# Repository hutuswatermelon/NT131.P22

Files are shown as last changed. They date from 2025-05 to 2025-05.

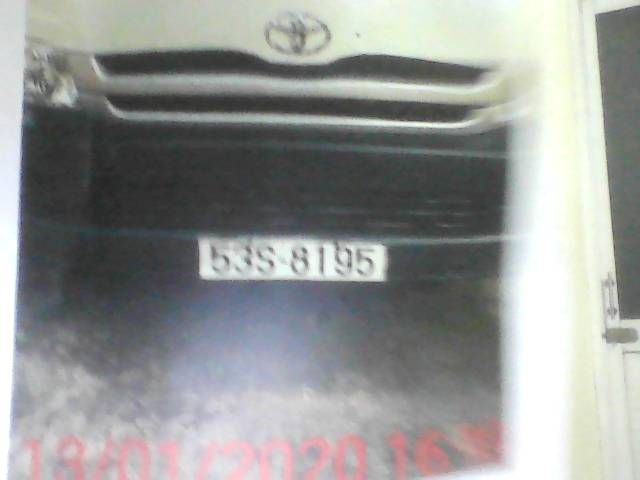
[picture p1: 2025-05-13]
back_end/uploads/1746991411067-entry-1746991411064.jpg

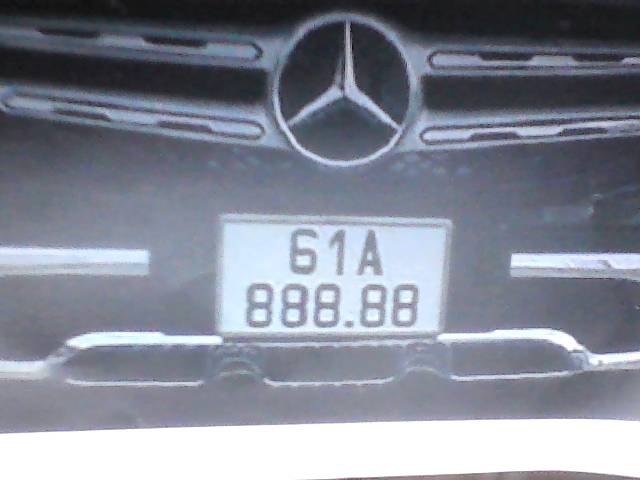
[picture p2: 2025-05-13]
back_end/uploads/1746958516057-entry-1746958516046.jpg

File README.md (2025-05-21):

# HỆ THỐNG BÃI ĐỖ XE TỰ ĐỘNG SỬ DỤNG ESP8266

## Thông tin môn học
- **Môn học:** Hệ thống nhúng mạng không dây
- **Mã lớp:** NT131.P22

## Thành viên nhóm
- Cáp Hữu Tú - 23521696
- Huỳnh Ngọc Ngân Tuyền - 23521753
- Nguyễn Tài Quang - 23521287

## Mô tả dự án
Dự án "Hệ thống bãi đỗ xe tự động" được xây dựng nhằm mô phỏng và triển khai một giải pháp quản lý bãi đỗ xe thông minh. Hệ thống sử dụng công nghệ RFID để xác thực xe vào/ra, kết hợp với nhận dạng biển số xe tự động qua camera. Trạng thái của bãi xe, thông tin xe, và các thao tác quản lý được hiển thị và điều khiển thông qua một giao diện web trực quan.

## Công nghệ sử dụng
- **Phần cứng:**
    - ESP8266 (NodeMCU 1.0 (ESP-12E Module)
    - Đầu đọc RFID MFRC522 và thẻ RFID
    - Động cơ Servo để điều khiển rào chắn (barrier)
    - Cảm biến hồng ngoại để phát hiện trạng thái đỗ xe (trong mô hình này, trạng thái chỗ đỗ được cập nhật từ ESP8266 dựa trên logic vào/ra kết hợp quét chỗ đỗ định kỳ).
    - Webcam để chụp ảnh biển số.
- **Phần mềm:**
    - **Arduino/C++:** Lập trình cho ESP8266 ([Arduino/car_parking/car_parking.ino](Arduino/car_parking/car_parking.ino)).
    - **Node.js & Express.js (Backend):** Xây dựng API, xử lý logic nghiệp vụ, giao tiếp với ESP8266, quản lý cơ sở dữ liệu, và phục vụ Server-Sent Events (SSE) ([back_end/server.js](back_end/server.js)).
    - **MongoDB:** Cơ sở dữ liệu NoSQL để lưu trữ thông tin xe, lịch sử vào ra.
    - **HTML, CSS, JavaScript (Frontend):** Giao diện người dùng tương tác với hệ thống ([front_end/index.html](front_end/index.html), [front_end/frontend.js](front_end/frontend.js), [front_end/style.css](front_end/style.css)).
    - **Python & FastAPI (License Plate Recognition Service):** Dịch vụ API riêng biệt để nhận dạng ký tự từ ảnh biển số xe ([back_end/License-Plate-Recognition/plate_recognition_service.py](back_end/License-Plate-Recognition/plate_recognition_service.py)).
- **Giao tiếp:**
    - HTTP requests (ESP8266 <-> Node.js, Frontend <-> Node.js, Node.js <-> Python LPR Service).
    - Server-Sent Events (Node.js -> Frontend) để cập nhật dữ liệu thời gian thực.

## Tính năng chính
- **Quản lý xe vào/ra:**
    - Xác thực xe qua thẻ RFID.
    - Tự động chụp ảnh và nhận dạng biển số xe khi xe vào/ra.
    - So sánh biển số xe vào và biển số đăng ký.
    - So sánh biển số xe ra với biển số đã ghi nhận lúc vào.
    - Điều khiển rào chắn tự động.
- **Quản lý bãi xe:**
    - Hiển thị số chỗ trống, số chỗ đã chiếm dụng.
    - Hiển thị danh sách xe đang có trong bãi.
    - Ghi nhận lịch sử các lượt gửi xe (thời gian vào, thời gian ra, biển số, RFID).
- **Giao diện người dùng (Web):**
    - Hiển thị hình ảnh camera (giả lập qua webcam client-side).
    - Hiển thị thông tin biển số xe vào/ra, hình ảnh biển số.
    - Cập nhật trạng thái bãi xe và danh sách xe theo thời gian thực.
    - Cho phép quản lý viên thao tác thủ công (ví dụ: mở cổng, chuyển chế độ RFID).
    - Chức năng xóa toàn bộ dữ liệu xe và lịch sử.
- **Tích hợp module nhận dạng biển số:**
    - Sử dụng một service Python riêng biệt để xử lý nhận dạng biển số.

## Trích dẫn phần Project được sử dụng cho nhận diện biển số
    https://github.com/buiquangmanhhp1999/License-Plate-Recognition

## Hướng phát triển tương lai
**Phần cứng:**
 - *Nâng cấp bộ xử lý trung tâm:*
    - Thay thế ESP8266 bằng ESP32 hoặc bộ xử lý mạnh hơn tuỳ vào quy mô bãi đỗ nhằm cải thiện hiệu suất điều khiển và khả năng xử lý dữ liệu.

- *Mở rộng hệ thống vào/ra:*
    - Thiết kế hệ thống có 2 cổng vào và 2 cổng ra để tăng lưu lượng xe và tối ưu hóa luồng giao thông.

- *Tích hợp camera AI:*
    - Nhận diện biển số: Sử dụng camera mini kết hợp với thuật toán học máy để nhận diện biển số xe tự động.
    - Giám sát toàn bãi xe: Camera giám sát toàn cảnh kết hợp AI nhằm phát hiện và nhận diện chính xác các xe đang đỗ, kể cả khi bị che khuất bởi vật thể khác.

- *Cảm biến môi trường:*
    - Cảm biến ánh sáng: Tự động bật/tắt hệ thống chiếu sáng theo điều kiện ánh sáng môi trường.
    - Cảm biến nhiệt: Kết hợp hệ thống cảnh báo và kích hoạt hệ thống phòng cháy chữa cháy khi phát hiện nhiệt độ bất thường.

- *Mở rộng mô hình bãi giữ xe phân tầng:*
    - Hỗ trợ quản lý bãi xe nhiều tầng, tích hợp bản đồ định vị ô đỗ xe và ghi nhớ vị trí xe đã đỗ.

**Phần mềm:**
- *Cho quản lý bãi xe:*
    - Quản lý đồng thời nhiều bãi đỗ xe.
    - Theo dõi tình trạng bãi xe theo thời gian thực.
    - Hỗ trợ điều khiển các chức năng của bãi xe từ xa thông qua phần mềm quản lý.

- *Cho người dùng (người cần đỗ xe):*
    - Ứng dụng di động thân thiện, tích hợp GPS.
    - Ứng dụng AI/học máy để gợi ý các bãi đỗ gần nhất còn trống, đồng thời cân nhắc chi phí đỗ xe phù hợp.
    - Cho phép người dùng đăng ký và giữ chỗ đỗ xe trực tuyến trước hoặc ngay khi đến bãi đỗ.

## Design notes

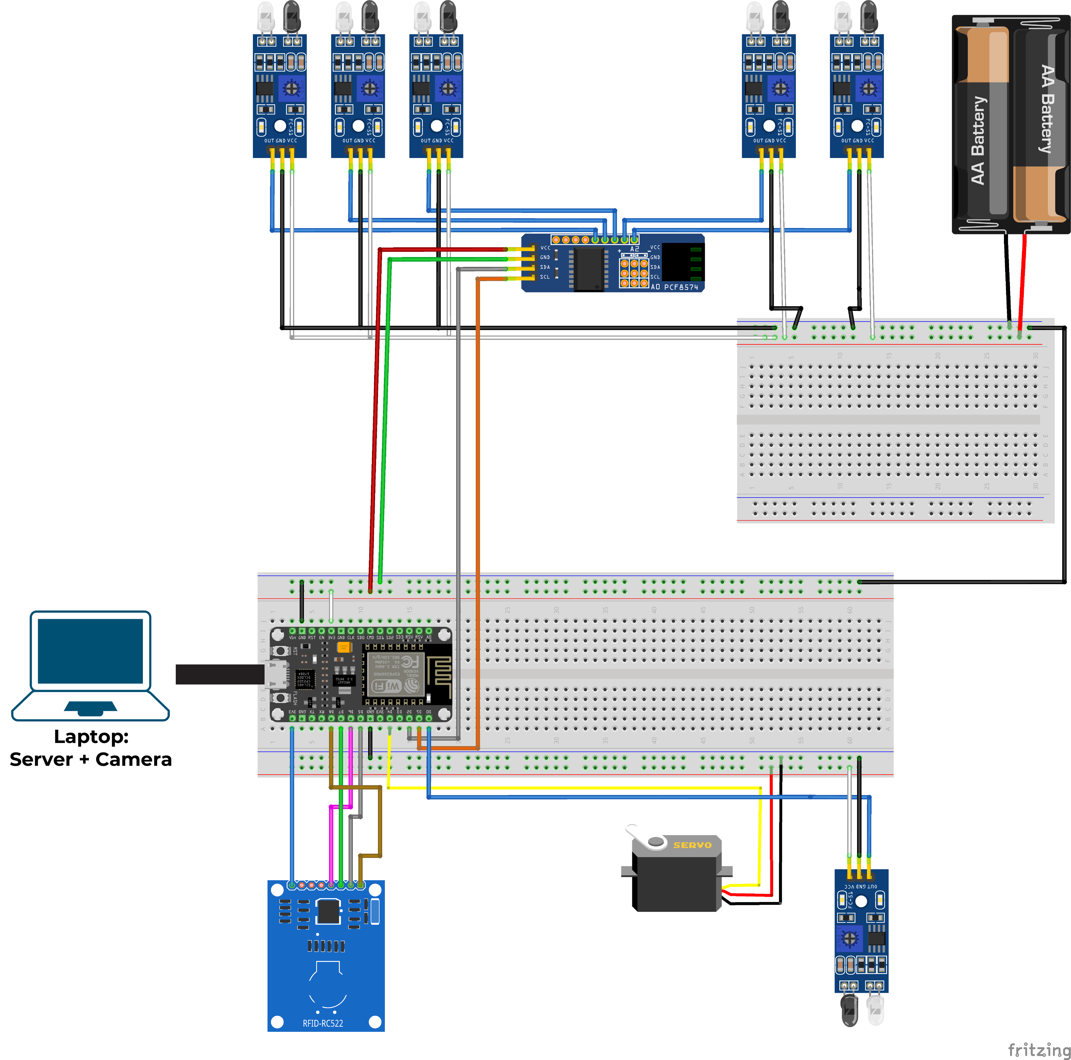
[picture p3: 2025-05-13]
Breadboard.png

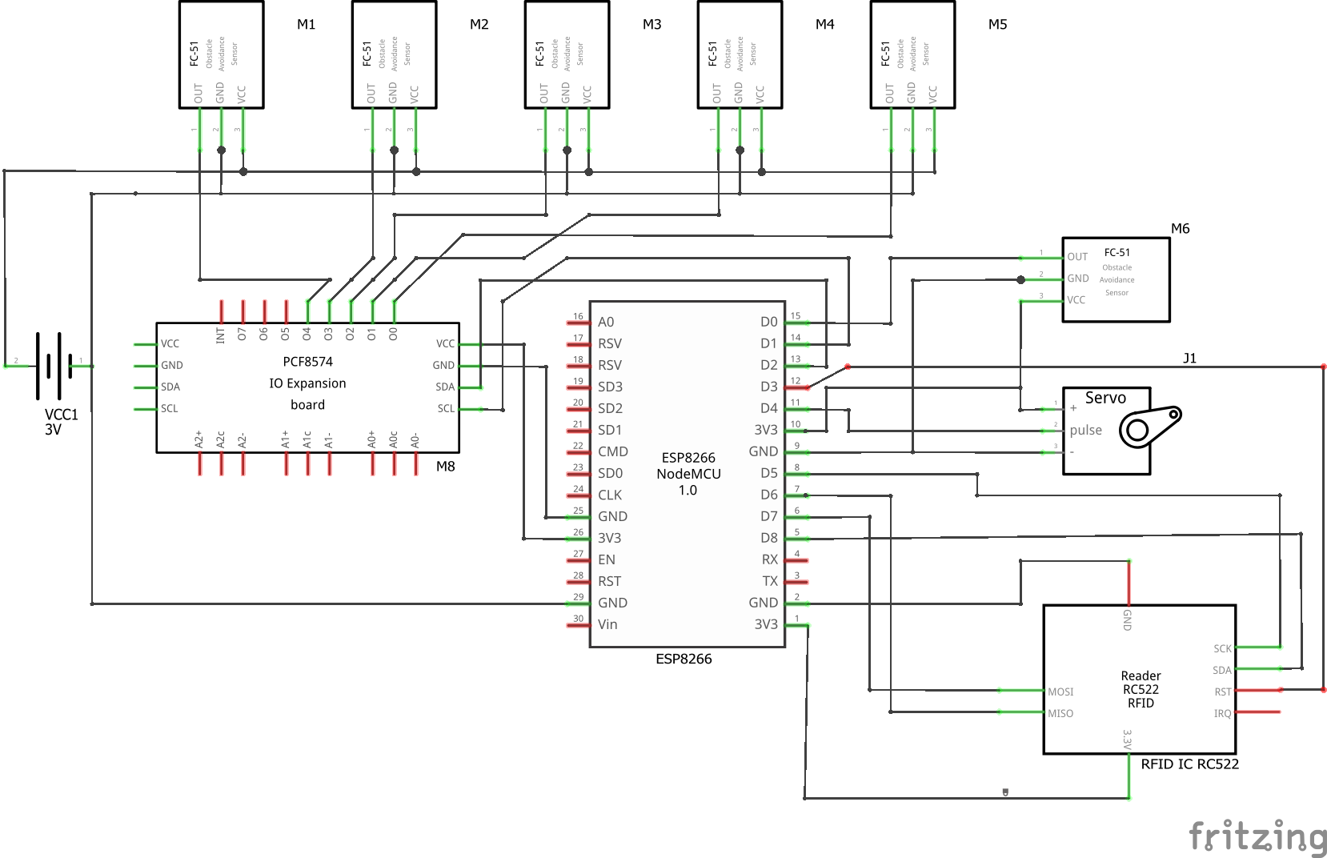
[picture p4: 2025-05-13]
Sơ đồ nguyên lý.png

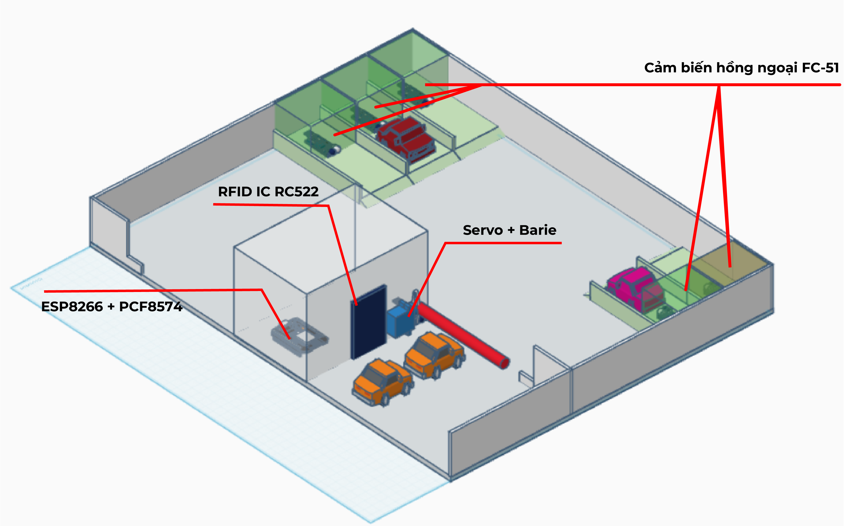
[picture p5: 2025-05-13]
Mô hình.png

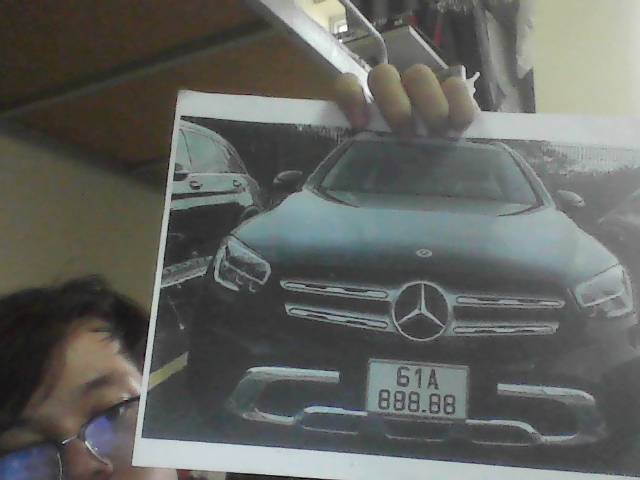
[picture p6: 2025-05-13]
back_end/uploads/1747042774266-entry-1747042774261.jpg

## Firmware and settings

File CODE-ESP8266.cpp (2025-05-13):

#include <ESP8266WiFi.h>
#include <ESP8266HTTPClient.h>
#include <WiFiClient.h>
#include <SPI.h>
#include <MFRC522.h>
#include <Wire.h>
#include <Servo.h>
#include <PCF8574.h> 
#include <ArduinoJson.h>
#include <ESP8266WebServer.h> // Added for ESP to act as a server

// ====== CONFIGURATION ======
const char* WIFI_SSID     = "CPS";
const char* WIFI_PASSWORD = "2444nam678";
const char* SERVER_HOST   = "http://192.168.243.134:3000";

WiFiClient client;

// PCF8574 I/O Expander
PCF8574 pcf8574(0x20);

#define ir_open  D0 // OUT - GPIO16 (D0 trên NodeMCU)

// RFID
#define RST_PIN  D3 // RST MFRC522 - GPIO0 (D3 NodeMCU)
#define SS_PIN   D8// SS (SDA/CS) MFRC522 - GPIO15 (D8 NodeMCU - Hardware CS)
MFRC522 mfrc522(SS_PIN, RST_PIN);

// Servo
#define SERVO_OPEN_GATE_PIN  D4 //  GPIO2 (D4 NodeMCU)
Servo openGateServo;

// ESP Web Server
ESP8266WebServer espHttpServer(80); // ESP will listen on port 80 for commands

// Constants
#define MAX_SLOT 5
#define BARRIER_CLOSED  150
#define BARRIER_OPENED  0

// Represents occupied state for the string (sensor LOW means occupied)
#define SLOT_STATE_OCCUPIED '1'
#define SLOT_STATE_EMPTY    '0'

#define HTTP_TIMEOUT 15000
int slot = 0;
bool waitingToCloseOpen = false;
unsigned long openStartTime = 0;

String uidToString(MFRC522& reader) {
  String s = "";
  for (byte i = 0; i < reader.uid.size; i++) {
    if (reader.uid.uidByte[i] < 0x10) s += "0";
    s += String(reader.uid.uidByte[i], HEX);
  }
  s.toUpperCase();
  return s;
}

// Notify server and get slots
// Changed endpoint to /api/rfid-request
bool notifyServer(const char* path, const String& uid, int &updated_slots_from_server) { 
  if (WiFi.status() != WL_CONNECTED) {
    Serial.println("WiFi not connected. Cannot notify server.");
    return false;
  }

  HTTPClient http;
  WiFiClient client; 

  String url = String(SERVER_HOST) + path + "?uid=" + uid;
  Serial.println("Sending to server: " + url); 

  http.begin(client, url);
  http.setTimeout(HTTP_TIMEOUT); 
  int httpCode = http.GET();

  bool openGateStatus = false;
  String serverMessage = "No response or error";

  if (httpCode > 0) {
    Serial.printf("[HTTP] GET... code: %d\n", httpCode);
    String payload = http.getString(); // Get payload for debugging
    Serial.println("Raw server response: " + payload);

    if (httpCode == HTTP_CODE_OK) {
      DynamicJsonDocument doc(512);
      DeserializationError error = deserializeJson(doc, payload);

      if (error) {
        Serial.print(F("deserializeJson() failed: "));
        Serial.println(error.f_str());
        serverMessage = "JSON parsing error";
      } else {
        openGateStatus = doc["openGate"] | false;
        updated_slots_from_server = doc["slots"] | -1; // Default to -1 if not present
        serverMessage = doc["message"] | "No message from server";
        String plate = doc["licensePlate"] | "N/A";
        // Log more details from server if available (e.g., for exit)
        if (doc.containsKey("fee")) {
            int fee = doc["fee"];
            serverMessage += " Plate: " + plate + ". Fee: " + String(fee) + " VND.";
        } else {
            serverMessage += " Plate: " + plate + ".";
        }
      }
    } else { // Handle other HTTP codes e.g. 400, 404, 500
        serverMessage = "Server error: HTTP " + String(httpCode);
        DynamicJsonDocument errorDoc(256);
        DeserializationError error = deserializeJson(errorDoc, payload);
        if (!error && errorDoc.containsKey("message")) {
            serverMessage = errorDoc["message"].as<String>();
        }
    }
  } else {
    Serial.printf("[HTTP] GET... failed, error: %s\n", http.errorToString(httpCode).c_str());
    serverMessage = "HTTP request failed: " + String(http.errorToString(httpCode).c_str());
  }
  http.end();
  
  Serial.println("Server final message: " + serverMessage);
  Serial.print("Open gate status: "); Serial.println(openGateStatus ? "Yes" : "No");
  Serial.print("Slots from server: "); Serial.println(updated_slots_from_server);

  return openGateStatus;
}

// Servo control
void openGate(Servo& gate) {
  gate.attach(SERVO_OPEN_GATE_PIN);
  Serial.println("Command received: Opening gate."); // Log manual open
  for (int pos = BARRIER_CLOSED; pos >= BARRIER_OPENED; pos -= 2) { // Assuming BARRIER_CLOSED is higher angle
    gate.write(pos);
    delay(20);
  }
  // After opening, set flags as if RFID opened it, to allow auto-close logic
  gate.detach();
  waitingToCloseOpen = true;
  openStartTime = millis();
  Serial.println("Gate opened manually. Waiting for auto-close conditions.");
}

void closeGate(Servo& gate) {
  gate.attach(SERVO_OPEN_GATE_PIN);
  Serial.println("Closing gate.");
  for (int pos = BARRIER_OPENED; pos <= BARRIER_CLOSED; pos += 2) { // Assuming BARRIER_OPENED is lower angle
    gate.write(pos);
    delay(20); 
  }
  gate.detach();
}

// Returns a string representing the state of each slot
// '1' for occupied, '0' for empty
String getIndividualSlotStatesString() {
  String states = "";
  Serial.println("--- Checking Individual Slot Status (PCF8574) ---");
  for (int i = 0; i < MAX_SLOT; i++) {
    uint8_t pinState = pcf8574.read(i); // Assuming LOW means sensor detected (occupied)
    if (pinState == LOW) {
      states += SLOT_STATE_OCCUPIED;
      Serial.print("Slot P"); Serial.print(i); Serial.println(" -> Occupied (1)");
    } else {
      states += SLOT_STATE_EMPTY;
      Serial.print("Slot P"); Serial.print(i); Serial.println(" -> Empty (0)");
    }
  }
  Serial.print("Individual Slot States String: "); Serial.println(states);
  Serial.println("---------------------------------------------");
  return states;
}

void sendSlotInfoToServer() {
  String slotStatesString = getIndividualSlotStatesString();

  if (WiFi.status() == WL_CONNECTED) {
    HTTPClient http;
    WiFiClient client; 
    // Send individual slot states AND ESP's IP address
    String espIP = WiFi.localIP().toString();
    String url = String(SERVER_HOST) + "/updateSlots?states=" + slotStatesString + "&total=" + String(MAX_SLOT) + "&ip=" + espIP;
    
    Serial.println("Sending individual slot states and IP to server: " + url);

    http.begin(client, url); 
    http.setTimeout(HTTP_TIMEOUT); 
    int code = http.GET();
    if (code > 0) {
        Serial.printf("[HTTP] Slot states update GET... code: %d\n", code);
        if (code == HTTP_CODE_OK) {
            String payload = http.getString();
            Serial.println("Slot states update server response: " + payload);
        }
    } else {
        Serial.printf("[HTTP] Slot states update GET... failed, error: %s\n", http.errorToString(code).c_str());
    }
    http.end();
    Serial.print("Individual slot states sent to server: ");
    Serial.println(slotStatesString);
  }
}

// Handler for manual gate control commands from Node.js server
void handleGateControl() {
  String action = espHttpServer.arg("action");
  Serial.print("ESP received /control-gate command. Action: ");
  Serial.println(action);

  if (action == "open") {
    openGate(openGateServo);
    espHttpServer.send(200, "text/plain", "Gate opening command received by ESP.");

  } else if (action == "close") {
    closeGate(openGateServo);
    waitingToCloseOpen = false;
    espHttpServer.send(200, "text/plain", "Gate closing command received by ESP.");
  }
  else {
    espHttpServer.send(400, "text/plain", "Invalid action. Use 'open' or 'close'.");
  }
}

void setup() {
  Serial.begin(115200);
  while (!Serial);
  Serial.println("\nBooting...");

  SPI.begin();
  mfrc522.PCD_Init();
  Serial.println("MFRC522 initialized.");

  WiFi.mode(WIFI_STA);
  WiFi.begin(WIFI_SSID, WIFI_PASSWORD);
  Serial.print("Connecting to WiFi ");
  Serial.print(WIFI_SSID);
  unsigned long wifiConnectStart = millis();
  while (WiFi.status() != WL_CONNECTED && millis() - wifiConnectStart < 15000) {
    delay(500);
    Serial.print(".");
  }
  if (WiFi.status() == WL_CONNECTED) {
    Serial.println("\nWiFi connected!");
    Serial.print("IP Address: ");
    Serial.println(WiFi.localIP());
  } else {
    Serial.println("\nWiFi connection FAILED. Check credentials or network.");
  }

  Wire.begin();

  if (pcf8574.begin()) {
    Serial.println("PCF8574 initialized successfully.");
  } else {
    Serial.println("PCF8574 initialization FAILED. Check wiring and I2C address (0x20).");
  }

  Serial.println("Configuring PCF8574 pins as inputs (writing HIGH)...");
    for (int i = 0; i < MAX_SLOT; i++) {
      pcf8574.write(i, HIGH); // Write HIGH to pin 'i' to set it as input with pull-up
      Serial.print("PCF8574 Pin P"); Serial.print(i); Serial.println(" set to input mode (HIGH written).");
    }

  openGateServo.attach(SERVO_OPEN_GATE_PIN);
  closeGate(openGateServo);
  Serial.println("Servo initialized and gate closed.");

  pinMode(ir_open, INPUT_PULLUP);
  int irOpen_state = digitalRead(ir_open);
  Serial.print("IR sensor pin initialized "); Serial.println(irOpen_state);

  Serial.println("System ready. Waiting for RFID card...");

  // Start ESP Web Server for commands
  espHttpServer.on("/control-gate", HTTP_GET, handleGateControl); // Listen for GET requests
  espHttpServer.begin();
  Serial.println("ESP HTTP server started for gate control commands on port 80.");
}

unsigned long lastUpdateTime = 0;
int server_reported_slots = 0;

void loop() {
  // Reconnect WiFi if needed
  if (WiFi.status() != WL_CONNECTED) {
    Serial.println("WiFi disconnected. Attempting to reconnect...");
    WiFi.begin(WIFI_SSID, WIFI_PASSWORD);
    unsigned long wifiReconnectStart = millis();
    while (WiFi.status() != WL_CONNECTED && millis() - wifiReconnectStart < 15000) { // Try for 15s
      delay(500);
      Serial.print('.');
    }
    if(WiFi.status() == WL_CONNECTED) {
        Serial.println("\nWiFi reconnected!");
        Serial.print("IP Address: "); Serial.println(WiFi.localIP());
    } else {
        Serial.println("\nWiFi reconnection failed.");
        delay(30000);
        return;
    }
  }

  espHttpServer.handleClient(); // Handle incoming HTTP requests for manual control

  // Check IR sensor for vehicle presence
  int irState = digitalRead(ir_open);

  if (!waitingToCloseOpen) { // Vehicle detected at gate, and gate is not already in an open-waiting-to-close cycle
    if (mfrc522.PICC_IsNewCardPresent() && mfrc522.PICC_ReadCardSerial()) {
      Serial.print("RFID Card detected. UID: ");
      String uid = uidToString(mfrc522);
      Serial.println(uid);

      // Call the updated server endpoint: /api/rfid-request
      if (notifyServer("/api/rfid-request", uid, server_reported_slots)) { 
        Serial.println("Access granted by server. Opening gate.");
        openGate(openGateServo);
        waitingToCloseOpen = true;
        openStartTime = millis();
      } else {
        Serial.println("Access denied by server or error occurred.");
      }

      mfrc522.PICC_HaltA();      // Halt PICC
      mfrc522.PCD_StopCrypto1(); // Stop encryption on PCD
      delay(1000); // Short delay to prevent immediate re-scan of the same card
    }
  }

  // Auto close gate after vehicle passes or timeout
  if (waitingToCloseOpen && 
      ( (millis() - openStartTime > 3000 && irState == HIGH) || (millis() - openStartTime > 10000) ) ) {
    Serial.println("Closing gate.");
    closeGate(openGateServo);
    waitingToCloseOpen = false;
    delay(500); // Delay after closing before being ready for new detection
  }
  
  // Send slot info to server periodically
  if (millis() - lastUpdateTime > 10000) { // Every 10 seconds
    sendSlotInfoToServer();
    lastUpdateTime = millis();
  }
  delay(100); // Small general delay in the loop
}
